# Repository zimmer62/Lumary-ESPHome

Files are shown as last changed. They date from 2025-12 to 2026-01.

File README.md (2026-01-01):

# Lumary ESPHome Gimbal Lighting

## Overview

This project provides ESPHome-based replacement firmware and hardware modifications for Lumary Smart Gimbal Recessed Lighting fixtures. These lights originally used proprietary cloud-dependent controllers. While there are hacks to install ESPHome on the original CBUs, they can be unreliable. This project replaces the stock microcontroller with an [ESP32-C6](images/original_post.jpg), enabling full local control via ESPHome and seamless integration with Home Assistant.

The hardware modification involves designing a custom PCB that serves as a drop-in replacement for the original controller board, allowing easy installation without extensive wires to solder. The firmware is built using ESPHome, providing robust WiFi connectivity and support for future Zigbee upgrades if desired.

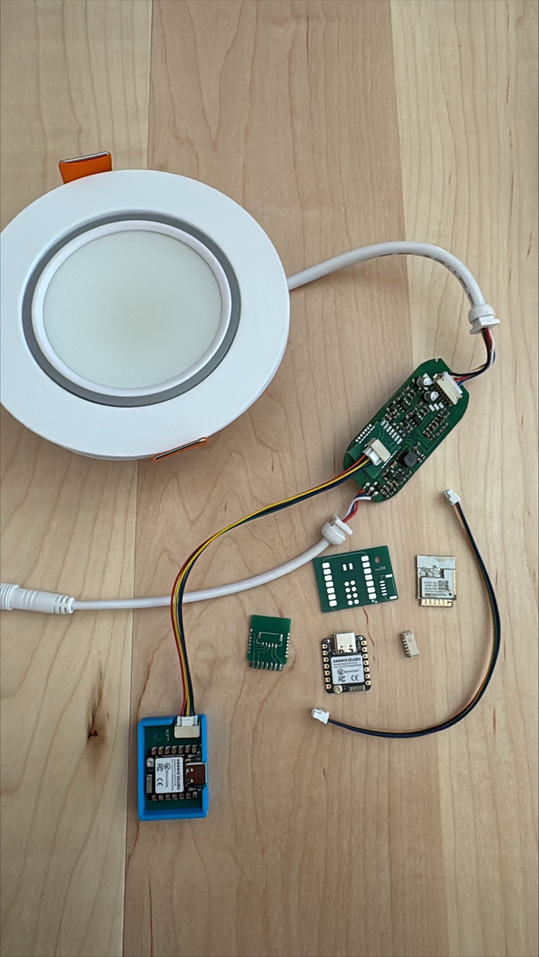
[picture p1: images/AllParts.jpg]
Original Lumary Controller Setup


## Features

- **Local Control**: Independent operation without reliance on manufacturer servers
- **Home Assistant Integration**: Native support for Home Assistant automation and control
- **[ESP32-C6](images/original_post.jpg) Compatibility**: Modern microcontroller with Wi-Fi and Bluetooth capabilities
- **Custom PCB Design**: Drop-in replacement board for simplified hardware modification
- **Open-Source Firmware**: Based on ESPHome for community-driven improvements
- **Hardware Mod**: Detailed instructions and files for replacing the stock microcontroller

## Repository Structure

- [`lumary_gimbal.yaml`](lumary_gimbal.yaml) - ESPHome configuration file for the Lumary gimbal lights
- `hardware/` - Hardware design files
  - `kicad/` - KiCad PCB design files
    - `CBU-Drop-in/` - Drop-in replacement PCB for original CBU (LearningTest2 files)
    - `CBU-Replacement-Daughterboard/` - Satellite board with ESP32-C6
  - `3d_models/` - 3D printable enclosure files (STL, OBJ formats)
- `images/` - Screenshots and diagrams
- `README.md` - This file

## Requirements

### Hardware
- Lumary Smart Gimbal Recessed Lighting fixture (typically 6-inch recessed cans)
- [ESP32-C6](images/original_post.jpg) microcontroller (Seeed Studio)
- Custom replacement PCB (designed for this project)
- Hot plate or ability to SMD solder tiny pads

### Software
- ESPHome

## Installation

### Hardware Modification
1. **Safety First**: Disconnect power and ensure the fixture is safe to work on.
2. **Disassemble**: Carefully open the controller box between the power supply and the light to access the internal controller board.
3. **Remove Stock CBU**: Locate and desolder the original microcontroller.
4. **Solder ESP32 and connectors**: Solder the connector to the drop-in board, and solder the ESP32 and a connector to the satellite board.
5. **Install Drop-In PCB**: Replace the original board with the custom [ESP32-C6](images/original_post.jpg) PCB designed for this project. The PCB is engineered as a drop-in replacement with matching pinouts.  
6. **3D print enclosure**: Print and install the ESP32 into the [3D-printed enclosure](hardware/3d_models).
7. **Connect the two boards**: Connect the two boards using the cable.
8. **Cut wire notch**: In the plastic case where the original controller was housed, notch out a space for the wires (e.g., using diagonal snips).
9. **Reassemble**: Put the case back together securely.

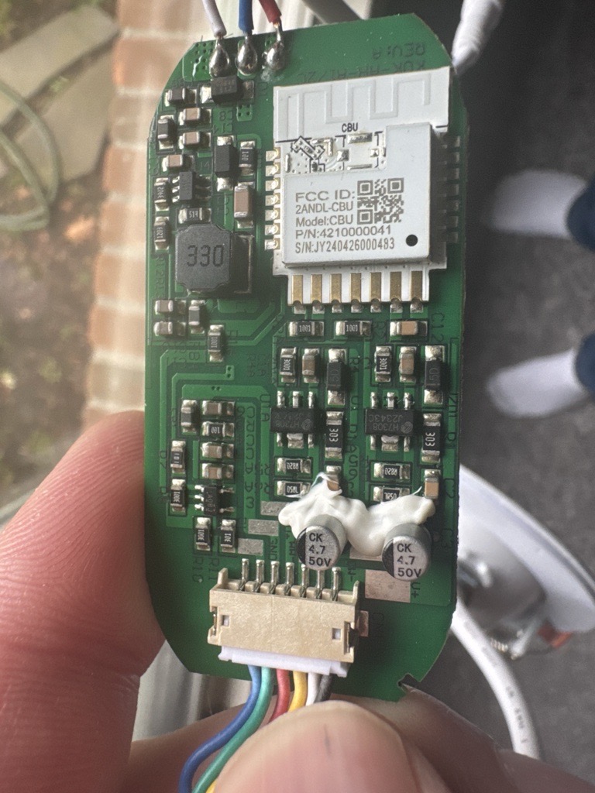
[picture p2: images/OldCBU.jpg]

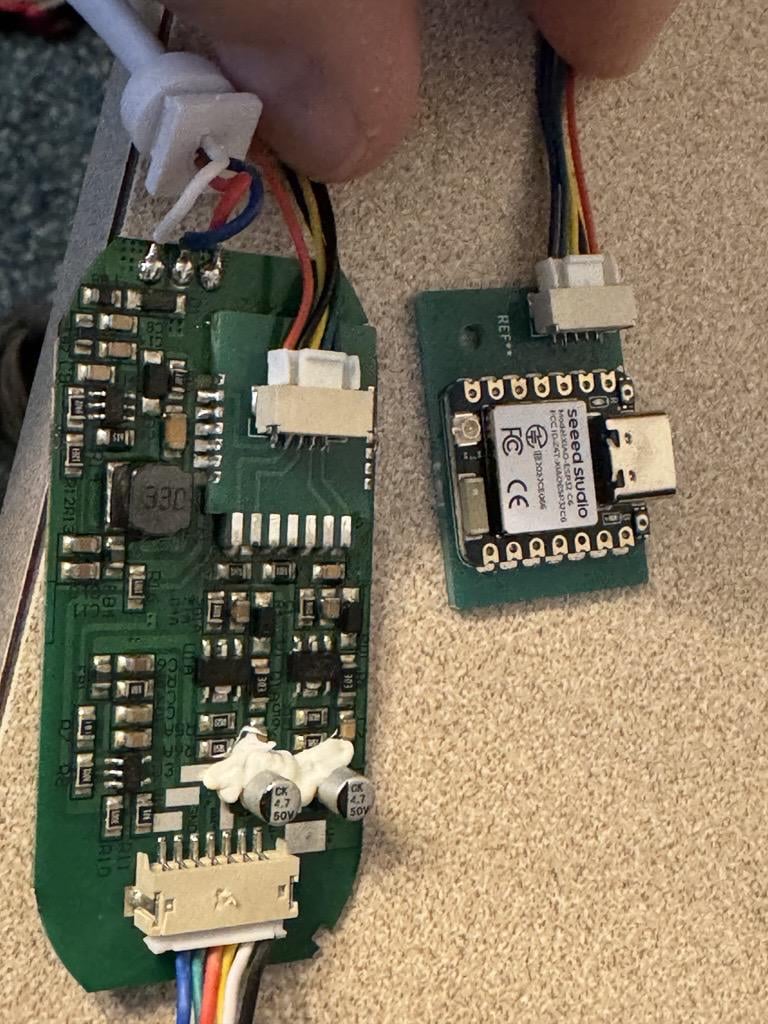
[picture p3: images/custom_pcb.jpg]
Custom ESP32-C6 PCB Replacement

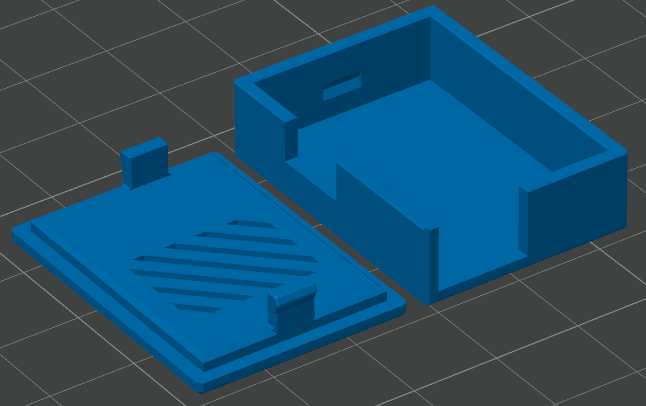
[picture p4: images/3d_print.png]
3D file


## Disclaimer

This project is provided as-is, without warranty. Hardware modifications carry risks including electrical shock, fire, or device damage. The authors are not responsible for any consequences of using this information. Lumary is a trademark of their respective owners.

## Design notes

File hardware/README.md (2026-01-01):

# Hardware

This directory contains all hardware design files for the Lumary ESPHome project.

## Structure

- **kicad/** - PCB design files for the controller boards
  - **CBU-Drop-in/** - Drop-in replacement PCB for the original CBU
  - **CBU-Replacement-Daughterboard/** - Satellite board that holds the ESP32-C6 module
- **3d_models/** - 3D printable enclosure and mounting files

## Overview

The hardware modification consists of two PCBs:

1. **Drop-in Board**: Replaces the original CBU board directly, maintaining the same form factor and connector pinouts
2. **Daughterboard**: A separate board that houses the ESP32-C6 module and connects to the drop-in board

This two-board approach allows for easier assembly and future upgrades to the ESP32 module.

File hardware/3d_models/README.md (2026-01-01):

# 3D Models

This directory contains 3D printable files for enclosures and mounting hardware.

3D Printed Enclosure

## Files

- **ESP32C6UpgradeBox.3mf** - Ready-to-print 3MF file for the ESP32-C6 daughterboard enclosure
- **ESP32C6UpgradeBox.f3d** - Autodesk Fusion 360 source file (editable)
- **ESP32C6UpgradeBox.step** - STEP file for CAD compatibility and modification

## Printing Recommendations

- Lay pieces on bed appropriately.

- Layer height: 0.2mm
- Infill: 20-30%
- Material: PLA or PETG
- Supports: Not Needed
- It's a pretty tight fit.

## Contributing

If you design or improve upon the enclosures, please consider contributing your STL files back to this project!

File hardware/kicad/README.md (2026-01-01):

# KiCad PCB Design Files

This directory contains KiCad project files for the Lumary ESPHome hardware modification.

## Projects

### CBU-Drop-in
Drop-in replacement PCB that replaces the original Lumary CBU (Control Board Unit). This board maintains the same form factor and connector pinouts as the original, allowing it to be installed without rewiring.

**Note**: The files are named "LearningTest2" as this was the working project name during development. These files represent the final CBU replacement PCB design.

### CBU-Replacement-Daughterboard
Satellite PCB that houses the ESP32-C6 module and connects to the drop-in board via a cable. This separation allows for easier ESP32 placement and future module upgrades.

## Manufacturing

Each project folder contains a `jlcpcb/` subdirectory with:
- `gerber/` - Gerber files for PCB manufacturing
- `production_files/` - BOM (Bill of Materials) and CPL (Component Placement List) for assembly

These files are ready to be uploaded to JLCPCB or other PCB manufacturers for production.

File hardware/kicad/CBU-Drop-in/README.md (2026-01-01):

# CBU Drop-in Replacement PCB

This is the main drop-in replacement PCB for the original Lumary CBU (Control Board Unit).

## Project Files

**Note**: The files in this directory are named "LearningTest2" - this was the working project name during development. These files represent the final design for the CBU replacement PCB.

- `LearningTest2.kicad_pcb` - PCB layout
- `LearningTest2.kicad_sch` - Schematic
- `LearningTest2.kicad_pro` - KiCad project file

## Manufacturing Files

- **jlcpcb/gerber/** - Gerber files ready for PCB fabrication
- **jlcpcb/production_files/** - BOM and CPL files for assembly services

## Design Features

- Drop-in replacement for original CBU board
- Maintains original connector pinouts and form factor
- Designed for easy installation without rewiring
- Connects to ESP32-C6 daughterboard via cable

## Library

The `Library.pretty/` folder contains custom footprints used in this design, including the CBU footprint that matches the original board dimensions.

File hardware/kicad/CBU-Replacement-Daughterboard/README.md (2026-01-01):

# CBU Replacement Daughterboard

This is the satellite PCB that houses the ESP32-C6 microcontroller module and connects to the drop-in replacement board.

## Project Files

- `CBU-Replacement-Daughterboard.kicad_pcb` - PCB layout
- `CBU-Replacement-Daughterboard.kicad_sch` - Schematic
- `CBU-Replacement-Daughterboard.kicad_pro` - KiCad project file

## Manufacturing Files

- **jlcpcb/gerber/** - Gerber files ready for PCB fabrication
- **jlcpcb/production_files/** - BOM and CPL files for assembly services

## Design Features

- Hosts the ESP32-C6 module
- Connects to the drop-in board via cable
- Designed to fit in a 3D-printed enclosure
- Allows for easier ESP32 placement and future module upgrades

## Assembly

This board requires:
1. ESP32-C6 module to be soldered
2. Connector to mate with the drop-in board cable
3. Optional: 3D-printed enclosure for protection and mounting

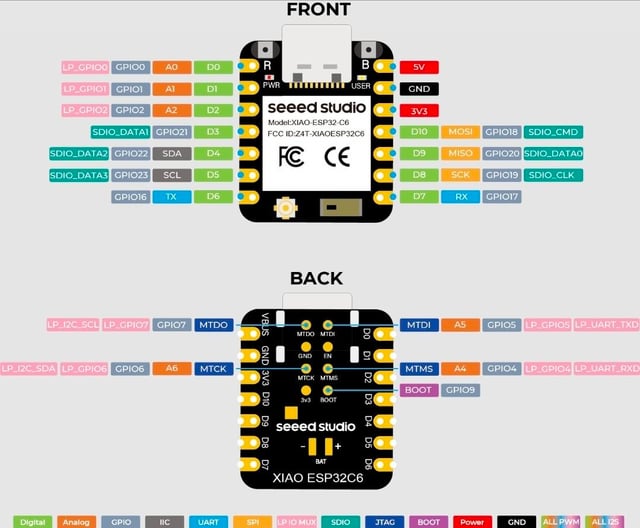
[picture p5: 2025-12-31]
images/original_post.jpg

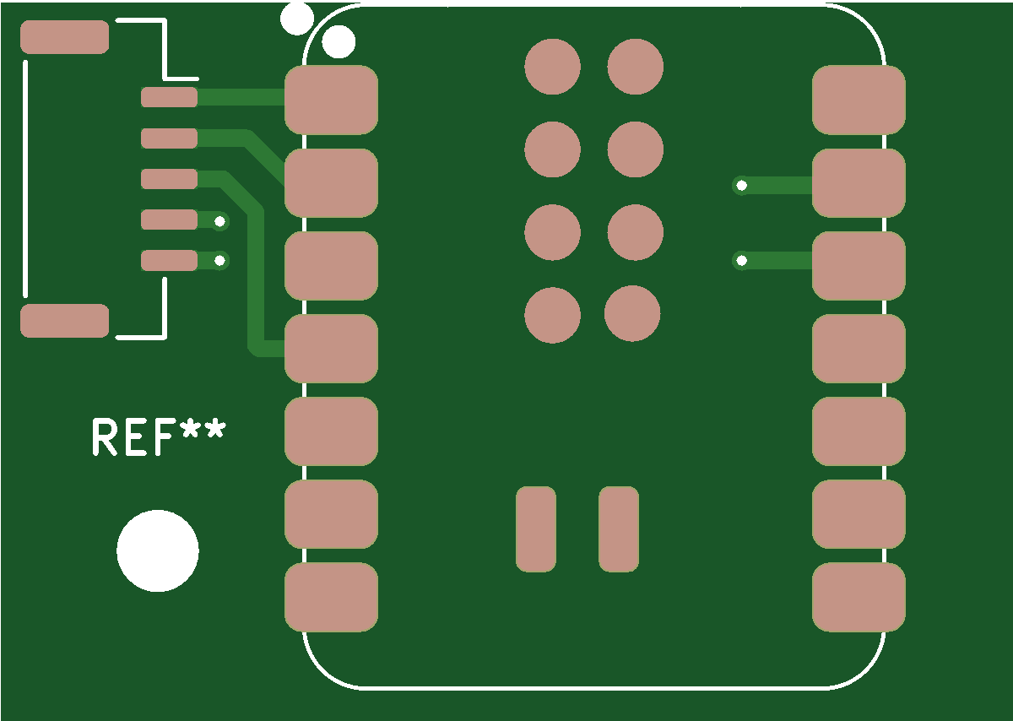
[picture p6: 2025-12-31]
images/esp_footprint.png

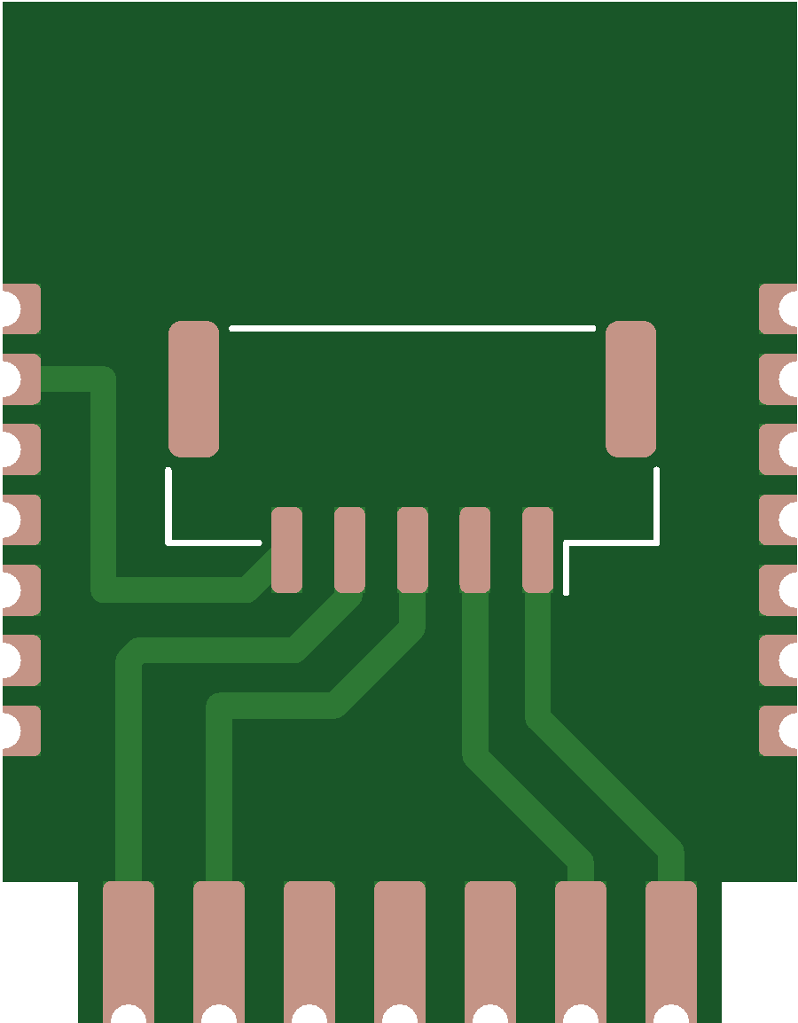
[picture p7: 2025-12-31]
images/cbu_footprint.png

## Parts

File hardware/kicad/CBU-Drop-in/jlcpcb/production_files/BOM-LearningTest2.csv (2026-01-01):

Comment | Designator | Footprint | LCSC | Quantity
Conn_01x05_MountingPin | J2 | JST_GH_SM05B-GHS-TB_1x05-1MP_P1.25mm_Horizontal |  | 1
CBU | U1 | CBU Footprint |  | 1

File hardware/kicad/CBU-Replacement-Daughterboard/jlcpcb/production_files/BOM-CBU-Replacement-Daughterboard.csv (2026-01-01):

Comment | Designator | Footprint | LCSC | Quantity
Conn_01x05_MountingPin | J1 | JST_GH_SM05B-GHS-TB_1x05-1MP_P1.25mm_Horizontal |  | 1
XIAO-ESP32-C6-SMD | U1 | XIAO-ESP32C6-SMD |  | 1

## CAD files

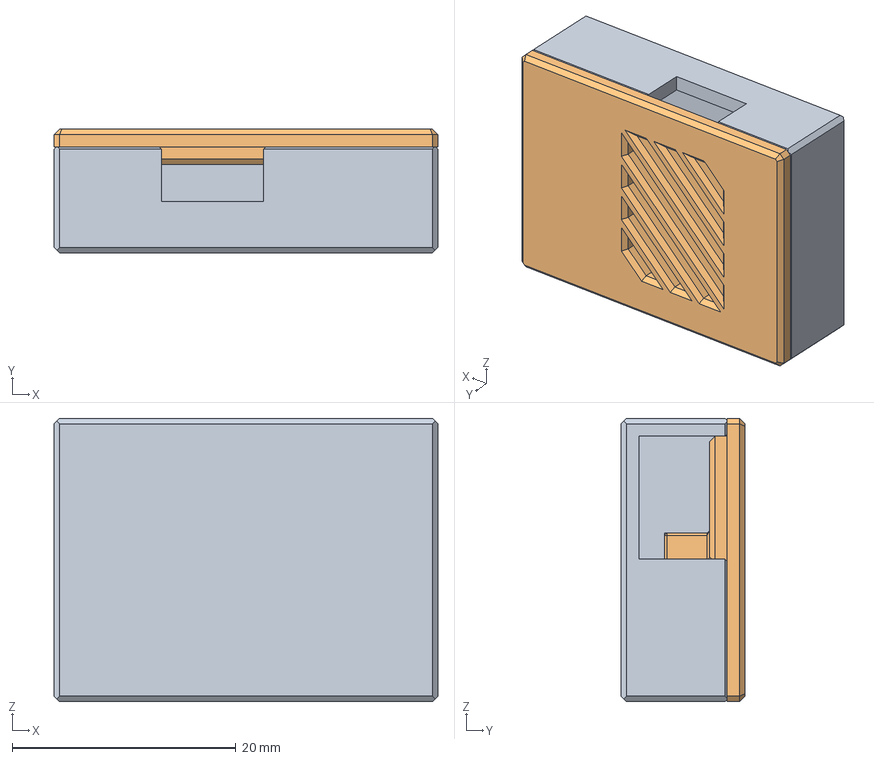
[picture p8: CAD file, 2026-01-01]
hardware/3d_models/ESP32C6UpgradeBox.step
34.4 x 11.1 x 25.4 mm

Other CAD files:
hardware/3d_models/ESP32C6UpgradeBox.3mf
hardware/3d_models/ESP32C6UpgradeBox.f3d

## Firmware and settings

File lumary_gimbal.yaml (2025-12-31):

esphome:
  name: "mud-room-accent-1"
  friendly_name: Mud Room Accent 1
esp32:
  board: esp32-c6-devkitc-1
  variant: esp32c6
  framework:
    type: esp-idf
# Enable logging
logger:
# Enable Home Assistant API
api:
  encryption:    
    key: !secret esphome_api_key
ota:
  - platform: esphome
    password: !secret ota_password
wifi:
  ssid: !secret wifi_ssid
  password: !secret wifi_password
  ap:
    ssid: !secret fallback_ssid
    password: !secret fallback_password
captive_portal:

# -----------------------------
#   OUTPUTS (PWM)
# -----------------------------
output:
  - platform: ledc
    id: output_cold
    pin: 1            # D0 → GPIO0
    frequency: 10000 Hz
  - platform: ledc
    id: output_warm
    pin: 21            # D1 → GPIO1
    frequency: 10000 Hz

# -----------------------------
#   LIGHTS (CWWW + RGB LED strip)
# -----------------------------
light:
  - platform: cwww
    id: light_cwww
    name: "Light"
    cold_white_color_temperature: 6500 K
    warm_white_color_temperature: 2700 K
    cold_white: output_cold
    warm_white: output_warm
  - platform: esp32_rmt_led_strip
    id: rgb_light_id
    name: "RGB Accent"
    chipset: SK6812
    rgb_order: RGB
    pin: 0              # D3 → GPIO21 (SAFE pin for timing LEDs)
    num_leds: 12
    gamma_correct: 1.0
    color_correct: [100%, 100%, 100%]
    effects:
      # Built-in effects
      - random:
          name: Random Colors
          transition_length: 5s
          update_interval: 3s
      - strobe:
          name: Strobe
          colors:
            - state: True
              brightness: 100%
              red: 100%
              green: 0%
              blue: 0%
              duration: 500ms
            - state: True
              brightness: 100%
              red: 0%
              green: 0%
              blue: 100%
              duration: 500ms
      - addressable_rainbow:
          name: Rainbow Effect
          speed: 10
          width: 50
      - addressable_scan:
          name: Scan Effect
          move_interval: 50ms
      - addressable_twinkle:
          name: Twinkle Effect
          twinkle_probability: 5%
      # Circular effect
      - addressable_lambda:
          name: Circular
          update_interval: 100ms
          lambda: |-
            static int position = 0;
            auto current_state = id(rgb_light_id).current_values;
            auto light_color = esphome::Color(
              current_state.get_red() * 255,
              current_state.get_green() * 255,
              current_state.get_blue() * 255
            );
            it.all() = esphome::Color(0, 0, 0);
            it[position] = light_color;
            position = (position + 1) % it.size();
      # Dual-circle effect
      - addressable_lambda:
          name: Circular Dual
          update_interval: 100ms
          lambda: |-
            static int position = 0;
            auto current_state = id(rgb_light_id).current_values;
            auto light_color = esphome::Color(
              current_state.get_red() * 255,
              current_state.get_green() * 255,
              current_state.get_blue() * 255
            );
            it.all() = esphome::Color(0, 0, 0);
            it[position] = light_color;
            int opposite_position = (position + it.size() / 2) % it.size();
            it[opposite_position] = light_color;
            position = (position + 1) % it.size();

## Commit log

2025-12-31 Add ESPHome configuration for Mud Room Accent 1 with CWWW and RGB LED strip support
    - Configured ESP32 board with logging, API, OTA, and WiFi settings
    - Defined PWM outputs for cold and warm white channels
    - Implemented CWWW light with adjustable color temperatures
    - Added RGB LED strip with multiple built-in effects including random colors, strobe, rainbow, scan, twinkle, and custom circular effects
2026-01-01 Add KiCad project files for Lumary ESPHome hardware modification
    - Created project database for CBU-Replacement-Daughterboard
    - Added README.md with project descriptions and manufacturing details
    [BOM-CBU-Replacement-Daughterboard.csv, BOM-LearningTest2.csv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]
2026-01-01 Refactor code structure for improved readability and maintainability
    [ESP32C6UpgradeBox.3mf]
2026-01-01 Add missing image for 3D printed enclosure in README
2026-01-01 Update printing recommendations in README for 3D models
